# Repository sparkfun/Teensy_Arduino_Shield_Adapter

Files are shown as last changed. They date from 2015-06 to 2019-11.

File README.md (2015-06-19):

SparkFun Teensy Arduino Shield Adapter
======================================

SparkFun Teensy Arduino Shield Adapter

[*SparkFun Teensy Arduino Shield Adapter (KIT-13288)*](https://www.sparkfun.com/products/13288)

This basic adapter kit enables you to use your Teensy 3.1 board with any standard Arduino Uno or Uno R3 compatible shields.

Repository Contents
-------------------
 
* **/Hardware** - Eagle design files (.brd, .sch)

Documentation
--------------
* **[Hookup Guide](https://learn.sparkfun.com/tutorials/teensy-arduino-shield-adapter-hookup-guideL)** - Basic hookup guide for the Teensy Arduino Shield Adapter.

License Information
-------------------
This product is _**open source**_! 

The **hardware** is released under [Creative Commons ShareAlike 4.0 International](https://creativecommons.org/licenses/by-sa/4.0/).

Please use, reuse, and modify these files as you see fit. Please maintain attribution to SparkFun Electronics and release anything derivative under the same license.

Distributed as-is; no warranty is given.

- Your friends at SparkFun.

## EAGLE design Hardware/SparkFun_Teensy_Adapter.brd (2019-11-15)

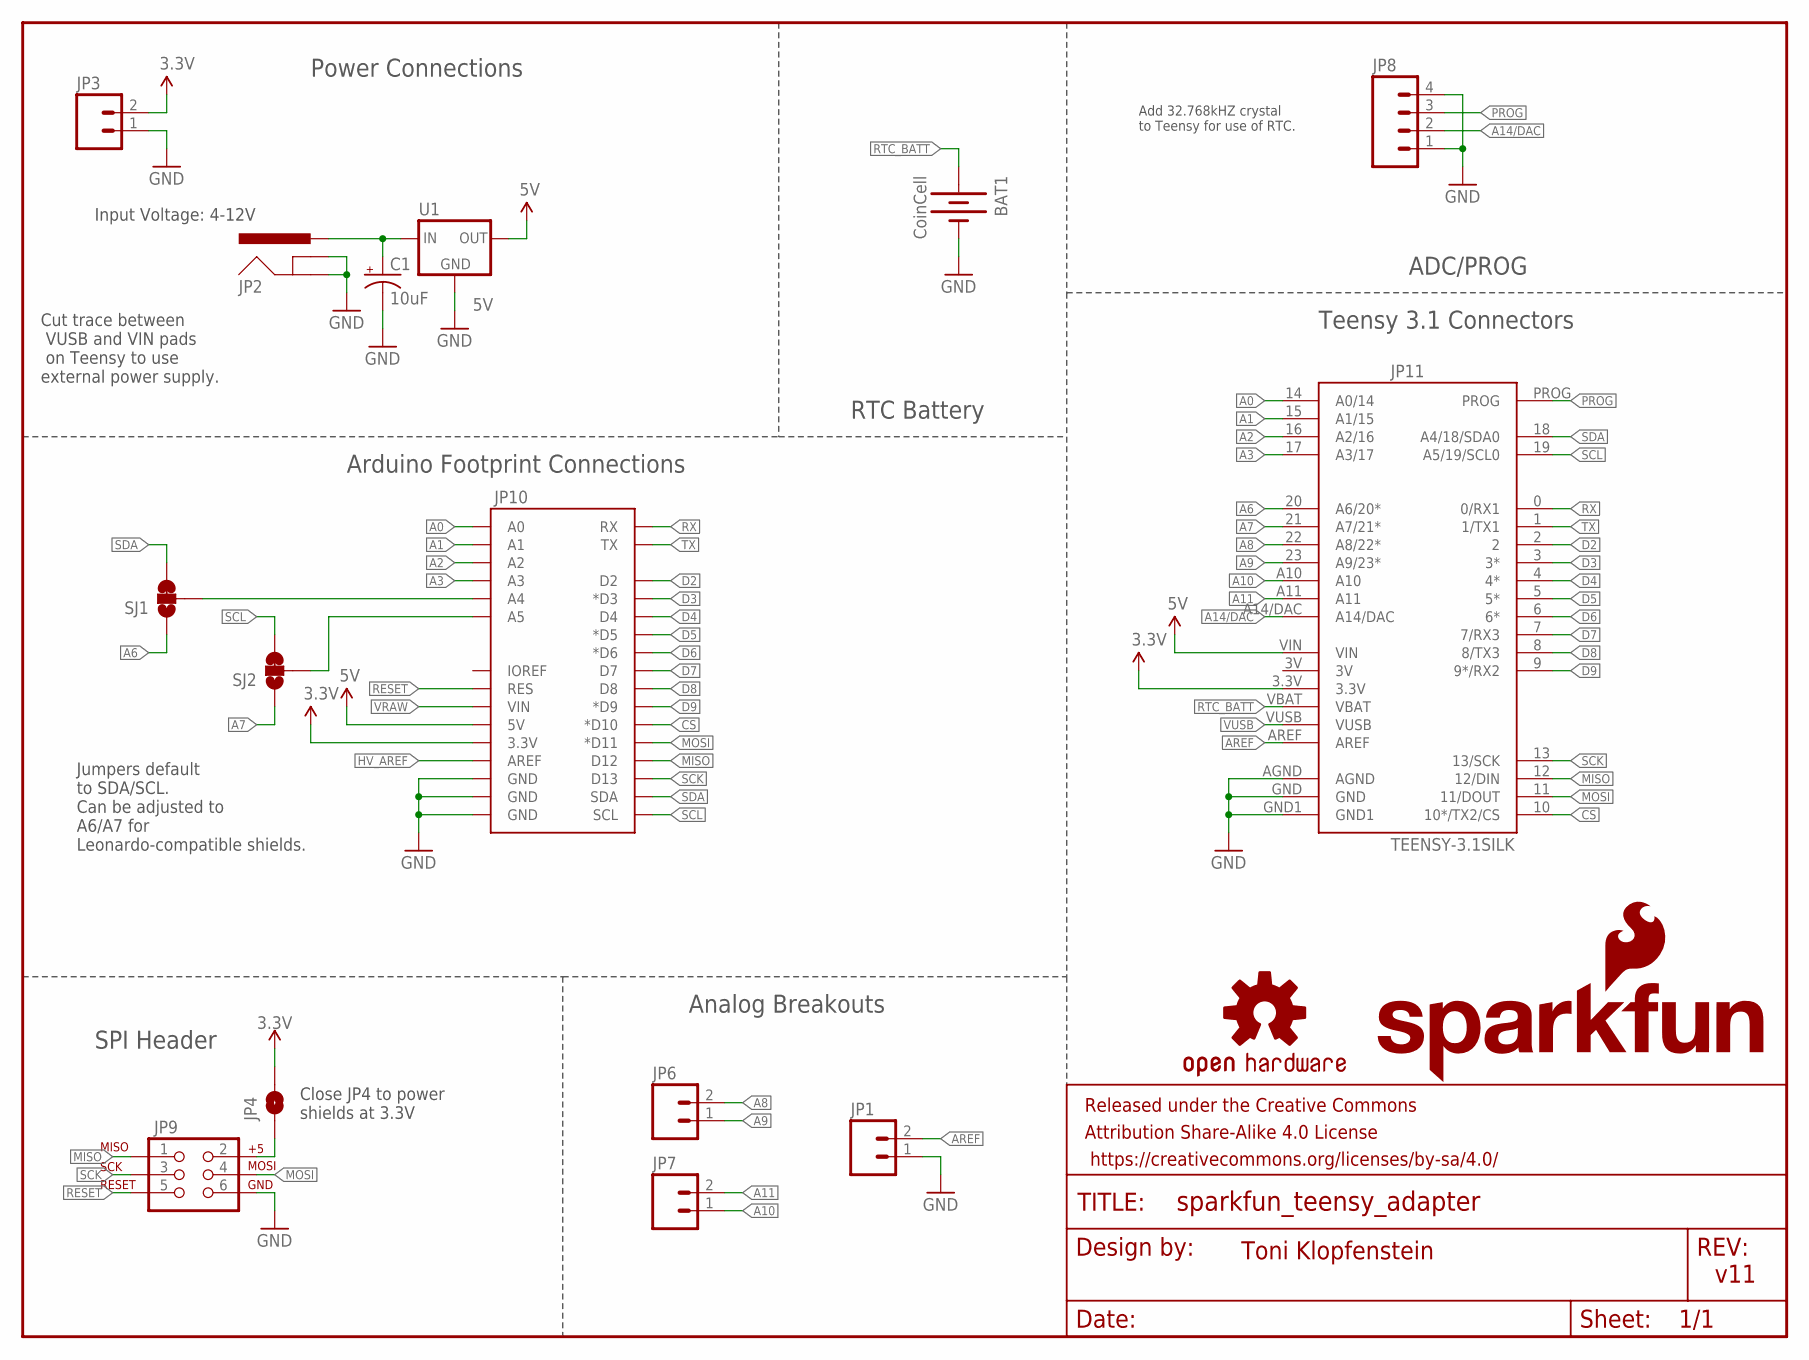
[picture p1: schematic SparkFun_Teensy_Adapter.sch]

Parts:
BAT1: CoinCell; BATTCON_12MM_PTH
C1: 10uF; CPOL-RADIAL-10UF-25V
FRAME1: FRAME-LETTER; CREATIVE_COMMONS
JP1, JP6, JP7: M02PTH; 1X02
JP2: POWER_JACKPTH_LOCK; POWER_JACK_PTH_LOCK
JP3: JST2; JST-2-PTH
JP4: JUMPER-SMT_2_NO_SILK; SMT-JUMPER_2_NO_SILK
JP8: M04PTH; 1X04
JP9: AVR_SPI_PRG_6PTH; 2X3
JP10: ARDUINO_R3_SHIELDUNO_R3_SHIELD_HOLES; UNO_R3_SHIELD_HOLES
JP11: TEENSY-3.1SILK; TEENSY-3.1
LOGO1: SFE_LOGO_NAME_FLAME.1_INCH; SFE_LOGO_NAME_FLAME_.1
LOGO2: OSHW-LOGOM; OSHW-LOGO-M
SJ1, SJ2: JUMPER-PAD-3-2OF3_NC_BY_TRACE_SMALL; PAD-JUMPER-3-2OF3_NC_BY_TRACE_YES_SILK_FULL_BOX
U1: 5V; TO-220-ALT

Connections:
3.3V: JP3.2, JP4.2, JP10.3.3V, JP11.3.3V
5V: JP10.5V, JP11.VIN, U1.OUT
A0: JP10.A0, JP11.14 (A0/14)
A1: JP10.A1, JP11.15 (A1/15)
A2: JP10.A2, JP11.16 (A2/16)
A3: JP10.A3, JP11.17 (A3/17)
A4: JP10.A4, SJ1.2
A5: JP10.A5, SJ2.2
A6: JP11.20 (A6/20*), SJ1.1
A7: JP11.21 (A7/21*), SJ2.1
A8: JP6.2, JP11.22 (A8/22*)
A9: JP6.1, JP11.23 (A9/23*)
A10: JP7.1, JP11.A10
A11: JP7.2, JP11.A11
A14/DAC: JP8.2, JP11.A14/DAC
AREF: JP1.2, JP11.AREF
CS: JP10.D10 (*D10), JP11.10 (10*/TX2/CS)
D2: JP10.D2, JP11.2
D3: JP10.D3 (*D3), JP11.3 (3*)
D4: JP10.D4, JP11.4 (4*)
D5: JP10.D5 (*D5), JP11.5 (5*)
D6: JP10.D6 (*D6), JP11.6 (6*)
D7: JP10.D7, JP11.7 (7/RX3)
D8: JP10.D8, JP11.8 (8/TX3)
D9: JP10.D9 (*D9), JP11.9 (9*/RX2)
GND: BAT1.GND (-), C1.2 (-), JP1.1, JP2.GND, JP2.GNDBREAK, JP3.1, JP8.1, JP8.4, JP9.6, JP10.GND@0 (GND), JP10.GND@1 (GND), JP10.GND@2 (GND), JP11.AGND, JP11.GND, JP11.GND1, U1.GND
HV_AREF: JP10.AREF
MISO: JP9.1, JP10.D12, JP11.12 (12/DIN)
MOSI: JP9.4, JP10.D11 (*D11), JP11.11 (11/DOUT)
unnamed: JP4.1, JP9.2
PROG: JP8.3, JP11.PROG
RESET: JP9.5, JP10.RES
RTC_BATT: BAT1.VCC@1 (+), JP11.VBAT
RX: JP10.RX, JP11.0 (0/RX1)
SCK: JP9.3, JP10.D13, JP11.13 (13/SCK)
SCL: JP10.SCL, JP11.19 (A5/19/SCL0), SJ2.3
SDA: JP10.SDA, JP11.18 (A4/18/SDA0), SJ1.3
TX: JP10.TX, JP11.1 (1/TX1)
VRAW: C1.1 (+), JP2.PWR, JP10.VIN, U1.IN
VUSB: JP11.VUSB

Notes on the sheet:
Input Voltage: 4-12V
Add 32.768kHZ crystal to Teensy for use of RTC.
Cut trace between VUSB and VIN pads on Teensy to use external power supply.
Jumpers default to SDA/SCL. Can be adjusted to A6/A7 for Leonardo-compatible shields.
Power Connections
Arduino Footprint Connections
SPI Header
Analog Breakouts
Teensy 3.1 Connectors
ADC/PROG
RTC Battery
v11
Toni Klopfenstein
Close JP4 to power shields at 3.3V

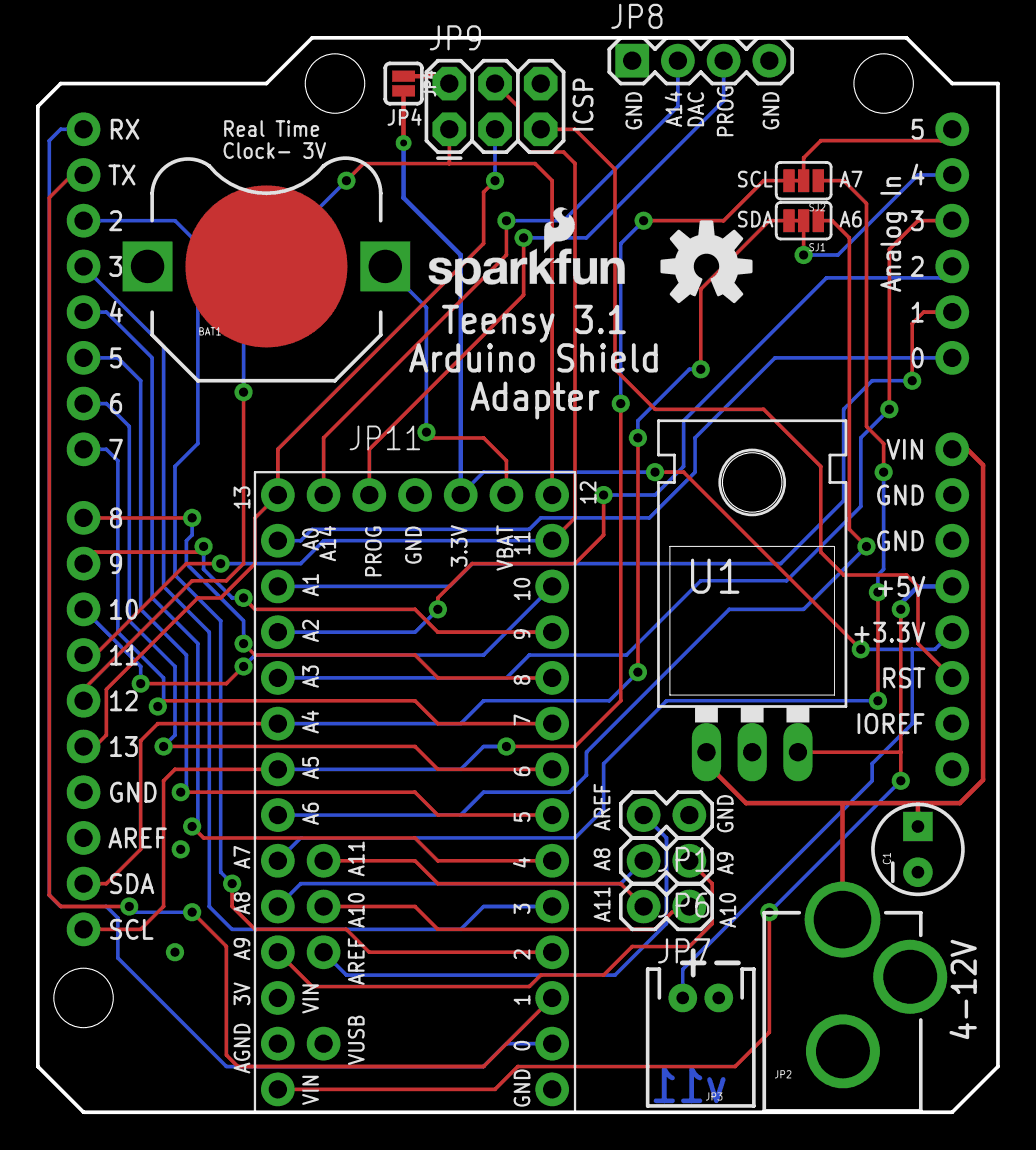
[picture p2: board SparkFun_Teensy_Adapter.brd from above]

Board: 2 copper layers, 53.3 x 59.7 mm, 18 parts (0 on the bottom side), 38 nets.

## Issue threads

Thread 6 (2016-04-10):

3.3V connection to SPI pin 2 (5V) destroys Arduino Ethernet shield

PaulStoffregen, 2016-04-10:
This PCB has a terrible design flaw.  When any shield with a 5V connection to pin 2 on the SPI connector is plugged in, the 3.3V and 5V power are shorted together.

Some shields, like older Arduino Ethernet, are **instantly destroyed** by the 5V power applied to their 3.3V circuits!  If all the Teensy pins are soldered, the **Teensy is also killed**.  Very bad.

The destructive path is: 5V power flows from the Teensy Adaptor to the shield on JP10 5V, then through wires on the shield to JP9 pin 2, where it then flow back to the Teensy Adaptor and causes the 3.3V power on the Teensy Adaptor to be driven up to 5V.  If the right-side pins of Teensy are soldered, the 3.3V only circuits on Teensy are destroyed.  The 5V power on the Teensy Adaptor's 3.3V line then flows through JP10 3.3V up to the shield, destroying any 3.3V only circuitry the shield may have.

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

Many modern shields leave SPI pin 2 unconnected.  But some do connect 5V to that pin.  :(

More discussion here:
https://forum.pjrc.com/threads/33280-W5100-Ethernet-shield-preventing-Teensy-3-2-from-reprogramming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

lewispg228, 2020-01-09:
Hey @PaulStoffregen ,
Sorry for this error in the design. We hope that it hasn't caused to much trouble for you. Thanks for submitting this issue.

We added an optional jumper in the latest revision (v11). It is now available to buy here:

https://www.sparkfun.com/products/15716

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

Thanks again and we hope this helps with your future projects!

PaulStoffregen, 2020-01-09:
Thanks for fixing this.  I'm sure it'll help many customers.

Closed 2020-01-09.

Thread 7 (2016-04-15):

IOREF Is Unconnected - Incompatible With Newer Arduino Shields

PaulStoffregen, 2016-04-15:
Newer shields, like [Arduino Wifi Shield 101](https://www.arduino.cc/en/uploads/Main/Arduino-WiFi101-schematic.pdf), require the IOREF pin to power buffers or signal level converters.  Those shields will not work with this adapter, because IOREF is unconnected.

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

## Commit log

2015-01-29 Initial hardware commit
    [SparkFun_Teensy_Adapter.brd, SparkFun_Teensy_Adapter.sch]
2015-01-30 Basic mechanical layout of board.
    [SparkFun_Teensy_Adapter.brd, SparkFun_Teensy_Adapter.sch]
2015-01-30 Power connectors added
    [SparkFun_Teensy_Adapter.brd, SparkFun_Teensy_Adapter.sch]
2015-01-30 Partial routing
    [SparkFun_Teensy_Adapter.brd, SparkFun_Teensy_Adapter.sch]
2015-02-02 Routing finished
    [SparkFun_Teensy_Adapter.brd, SparkFun_Teensy_Adapter.sch]
2015-02-03 Fixing DRC issues
    [SparkFun_Teensy_Adapter.brd]
2015-02-03 Fixing additional DRC errors, adding in board name to silk
    [SparkFun_Teensy_Adapter.brd]
2015-02-03 Adding switch for USB Host, RTC battery holder
    [SparkFun_Teensy_Adapter.brd, SparkFun_Teensy_Adapter.sch]
2015-02-11 Swapping to all PTH parts, fixing name silk
    [SparkFun_Teensy_Adapter.brd, SparkFun_Teensy_Adapter.sch]
2015-02-13 Fixing QC checklist issues
    [SparkFun_Teensy_Adapter.brd, SparkFun_Teensy_Adapter.sch]
2015-03-05 Fixing battery connections
    [SparkFun_Teensy_Adapter.brd, SparkFun_Teensy_Adapter.sch]
2015-03-30 Moving vias from under regulator, removing USB host shield parts
    [SparkFun_Teensy_Adapter.brd, SparkFun_Teensy_Adapter.sch]
2015-04-09 Updates for QC final review before reds
    [SparkFun_Teensy_Adapter.brd, SparkFun_Teensy_Adapter.sch]
2017-08-08 Value Changes for 3D Modeling
    [SparkFun_Teensy_Adapter.brd, SparkFun_Teensy_Adapter.sch]
2019-09-06 Remove ISP connection to 3.3V. Add NO jumper connection.
    Request by PaulS. When a shield was attached via SPI the 5V from the shield would kill the 3.3V Teensy.
    [SparkFun_Teensy_Adapter.brd, SparkFun_Teensy_Adapter.sch]
2019-11-15 Getting sch and brd consistant.
    [SparkFun_Teensy_Adapter.brd, SparkFun_Teensy_Adapter.sch]

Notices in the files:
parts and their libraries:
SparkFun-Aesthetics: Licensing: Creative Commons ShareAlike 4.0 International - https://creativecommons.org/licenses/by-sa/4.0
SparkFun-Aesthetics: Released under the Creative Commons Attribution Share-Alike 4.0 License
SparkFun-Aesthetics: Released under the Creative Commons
